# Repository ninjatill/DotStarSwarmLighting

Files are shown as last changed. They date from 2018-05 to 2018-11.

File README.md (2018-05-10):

# DotStar Swarm Lighting
Lighting objects made with "DotStar" LEDs which communicate with each other in a swarm.

**_This entire project is a major work-in-progress. The DotStar Swarm ecosystem has much potential but is worked on as a hobby. If you would like to contribute, submit an issue or pull request. Thanks for your interest!_**

## Concept and Background
This project was started with a desire to make a high-visual-impact decorations for use in public displays. The core component in all the display objects is the DotStar LED. DotStar is a name used by Adafruit for independently-addressable RBG LEDs using the APA102 chipset (2-wire SPI interface). A public display can have multiple DotStar objects which can be manipulated from a central controller over WiFi.

Why create this stuff? The inspiration came from a giant, 50+ foot-tall oak tree in my front yard. I want to decorate for the holidays but this tree is so massive it doesn't make sense to run strands of "twinkle" lights up into the tree. Twinkle lights are prone to burn-outs, you would need a hundred strands to make a visual impact in such a large tree, and as the tree grows the strands would need repositioned if wrapped around the trunk or branches. To start this idea, I first designed the "DotStar Ball" which was a fairly large, bright sphere of individually-addressable LEDs. The ball size I thought would have a proportionally large visual impact when compared to an ornament on say a standard-sized christmas tree. But one sphere in a large tree is not enough. So the idea was that I would make 10-20 of these balls and to add to the "cool-factor", they would need to have animations and be able to coordinate the animations amongst themselves or respond to external input.

## Major Project Components
There are numerous components to the project including:
- lighting objects (ball/sphere/cylinder, chain, etc.),

**_Not Yet Implemented_**
- local swarm controller (device on the swarm network that sends commands to objects),
- external swarm controller (server or cloud app where you can build animations and send them to the local controller or objects).

## Project Elements with Documentation

- [Communication Structure](/CommunicationStructure.md)
- [The DotStar Ball](/DotStarBall/README.md)

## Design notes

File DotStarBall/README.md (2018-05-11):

# DotStar Ball (aka. DotStar Sphere)
The first object designed for this swarm ecosystem is the DotStar Ball (DSB). See the [DotStar Swarm Lighting readme](/README.md) for a full overview of what this project is all about.

//Add animated gif or video...

#### Design Criteria
When I started designing this object, I used the some of these criteria:
- had to be large enough to have a visual impact hanging on a large tree branch,
- had to be (relatively) low cost since I had to make many of them,
- has to receive external commands and display animations from that input,
  - commands should request a particular effect or animation as opposed to addressing individual pixels,
- has to be addressable individually or in groups,
- has to function autonomously after receiving commands (similar to how the DotStar APA102 chipset functions).

#### Design Constraints
- Anything I create has to live outdoors. It has to be designed to operate in Northeastern US weather (snow, rain, high-winds, etc.)
- I knew I would be using DotStar LED strips. I used them for a previous project and found them easy to use and program. These strips optionally come with a silicone jacket with an IP67 rating which satisfies the weather issue. To keeps costs low and with a rough guestimate of the size of the sphere, I chose the version with 60 pixels/meter which would give me a pixel length of 16.67mm.
- I have a 3D printer so I knew that I would most-likely design and print a custom support structure to keep it light and low cost. I have an original Prusa i3 Mk2 printer with maximum print dimensions 250x200x180mm.
- I wanted the electronics to be accessible without completely disassembling the ball. Also, for best WiFi reception, the electronics should be located on the under-side of the ball.

## Particle Photon Demonstration
Makers who do not want to build the DSB may still benefit from some of the demonstrated methods on the Particle Photon platform including:
- parsing JSON strings on the IoT hardware,
- receiving and parsing variables sent via JSON where the JSON payload contains a varying number of variables,
- using a single Particle cloud subscription to address multiple devices, filtering commands by a target address,
- using the built in Log functionality, sending logs to an external service such as papertrailapp.com,
- using classes for object-oriented programming on IoT devices,
- using both UDP and particle cloud functions to receive commands.

## Roadmap (To Do Features) (In _Loose_ Order of Priority)
- Add firmware features (sleep, report status to controller, etc.)
- Finalize designs for electronics custom PCB, electronics housing and hanging bracket.
- Investigate using hardware timers to control animation processing intervals.
- Add temperature monitoring/fan control for the PSU.
- Add support for external hardware triggers.
- Add environmental monitoring hardware making each light a small weather station.
- Add support for [DMX-512](https://en.wikipedia.org/wiki/DMX512).
- Add support for [Light-O-Rama](http://www1.lightorama.com/) controllers.

## Bill of Materials
- [Particle Photon](https://www.particle.io/products/hardware/photon-wifi) ($20)
- 10 Meters of SK9822 or APA102 LEDs, 60 Pixels/Meter, Silicone-Jacketed (IP67), Black Flex PCB (~$10/meter) from [Adafruit](https://www.adafruit.com/product/2239), [AliExpress](https://www.aliexpress.com/item/1m-5m-APA102-Smart-led-pixel-strip-Black-White-PCB-24-36-60-96-leds-pixels/32322326979.html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,searchweb201602_1_10152_10151_10065_10344_10068_10130_10324_10342_10547_10325_10343_10546_10340_5722611_10548_10341_10545_10696_5722911_5722811_10084_5722711_10083_10618_10307_5711211_10059_308_100031_10103_10624_10623_10622_10621_10620_5711311_5722511,searchweb201603_2,ppcSwitch_2&algo_expid=6ef3fe06-63bb-41f2-b8bc-39bc1ad5b3ed-1&algo_pvid=6ef3fe06-63bb-41f2-b8bc-39bc1ad5b3ed&priceBeautifyAB=0)
  - Reels of LEDs should come with extra 4-Pin JST connectors for connecting the electronics PCB to the LED strip.
- 3D-Printed Support Structure (~$48 for 2kg of PETG) (see the [readme](/DotStarBall/stl/readme.md) for more details.)
  - PETG 1.75mm Filament from [MakerGeeks](https://www.makergeeks.com/collections/maker-series-petg)
    - Choose appropriate filament for your 3D printer or have a 3D printing service manufacture the printed objects for you.
- 5V, 40A Switching Power Supply ($25) from [Amazon](https://www.amazon.com/ALITOVE-Transformer-Converter-Security-Computer/dp/B077SYHQCJ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)
- 6 2-pin Power Connectors ($10) from [Amazon](https://www.amazon.com/TrendBox-Connector-Adapter-Electronics-Projects/dp/B0722SCRHM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)
- Multi-colored Hookup Wire (size appropriately and consider outdoor exposure when selecting). Alternatively, use 4-conductor LED ribbon cable (I will probably use [this](https://www.amazon.com/TronicsPros-65-6ft-Extension-Connector-Multicolor/dp/B015RLUAV0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) on subsequent DSBs but I wanted a larger wire gauge for the power rails and also the power and ground should be the outer-most connectors.)
- Clear Silicone Caulking
- Solder
- 64+ #6 1/2" Stainless Steel Screws from [Fastener Mart](https://www.fastenermart.com/SC165-1452.html)
- 16+ #6 3/4" Stainless Steel Screws from [Fastener Mart](https://www.fastenermart.com/SC165-3452.html)

## Similar Designs
I mostly had the support structure designed and fabricated prior to doing any kind of search for a similar idea or concept. I did find a few similar designs out there but none that fit my exact requirements. Most were stand-alone objects and higher in cost to fabricate. Here's a brief comparison:
- [Spherical LED Matrix](http://www.instructables.com/id/Spherical-LED-Matrix-Sphere-Shaped-LED-Screen-From/) This project is most closely related to what I'm trying to do. The maker used a metal support structure and oriented the pixel strips in a horizontal manner (which I found to be an unfavorable design.) The maker hides the non-uniform LED positioning by enclosing the entire structure in a translucent shell.
  - This design differs from the DSB in that the DSB is smaller, lighter, and WiFi enabled. Both projects are similarly (proportionally) priced. Additionally, this design uses specialized hardware and uses non-wireless communication protocols/hardware such as USB or DMX-512. It is not addressable in a swarm but could be modified to do so. The device cannot function on its own but rather takes constant input from a software controller; while this doesn't meet my design goals, use of off-the-shelf software means that more animations and effects are available without custom programming.
- [Giant LED Disco Ball](https://blog.hackster.io/get-the-party-started-with-this-giant-led-disco-ball-cd776451e3c0) This is a well designed project that used custom-printed PCBs to create a geodesic sphere. Each PCB housed a few Neopixels. The design is meant to be mobile and run off of large LiPo batteries.
  - This design differs from the DSB in that the DSB is smaller, lighter, cheaper to fabricate and WiFi enabled. It is not addressable in a swarm but could be modified to do so.
- [Neopixel LED EyeBall](https://www.hackster.io/H0meMadeGarbage/neopixel-led-eyeball-8da098)
  - This is just a few Neopixels taped to a half-sphere meant to be carried around. Not exactly a comparison but it does come up when you search google for "LED Sphere".
- Hackster.io and Youtube.com have some DIY POV-type cylindrical and spherical displays such as [this](https://www.hackster.io/hanoba_DIY/pov-cylinder-with-arduino-due-7016d5), [this](https://www.hackster.io/wslaton/easy-pov-display-9f4a88), [this](https://www.youtube.com/watch?v=sEY6N4HkSDM), [this](https://www.youtube.com/watch?v=-1Qe17flj0U), or [this](https://www.youtube.com/watch?v=Pf4IyXFTvT4). [This design](https://www.youtube.com/watch?v=_hprsvsPpEI) was a interesting take on the POV display but POV would not be reliable in the same environment as the DSB.
  - POV displays would not be practical to hang in a tree due to the moving parts and exposed electronics. Any slip joint would be prone to water infiltration.
- Youtube.com has some commercial displays that are similar such as [this](https://www.youtube.com/watch?v=te4uvfAzgXY), [this](https://www.youtube.com/watch?v=v2Eh44Rp4_Q), [this](https://www.youtube.com/watch?v=sEY6N4HkSDM), or [this](https://www.youtube.com/watch?v=mB8hct78ETk).
  - All these projects look terribly expensive and out of reach for the DIY community.

## Sequences/Modes/Animations
Read the [Communication Structure](/CommunicationStructure.md) document for a better understanding of Sequences, Commands, Command Elements, and Parameters.

The following section documents the animations available on the DSB. A mode and animation are virtualy synonomous. However, a mode can specify some non-animation commands such as "standby".

Animations are pre-built for the light strip. Each animation is governed by the list of parameters sent in the mode command. See this reference for a list of the parameter types. An animation can be as simple as turning on/off a single pixel. But an animation can be complex such as a pulse (fade from a start color to an end color and then back to the start color).

The "M" mode command can trigger the following animations:

- (0) Standby
  - Runs the All Off animation once then waits for incomming commands. ~~If a duration is specified, the Photon will sleep for the specified duration.~~ (consider putting sleep-on-standby on roadmap).
- (1) All Off
  - Turns all LEDS off.
- (2) Object On
  - Turns on objects specified in the object array. 
  - Defaults to "All" if no object array specified. Defaults to black (off) if no color array specified.
  - Optional Parameters: A, C, O
  
  //Add animated gif or video...

- (11) Fade
  - Fades from one color to the next. 
  - The colors change slightly between the start and end color on each step advance. The amount of change is based on the number of steps (T) specified and the start and end colors. 
  - If repeat (R) is specified, on each repeat, the next 2 color in the color array will be used. If there are more repeats than colors, the color array index will wrap around.
    - For example, using this color array `"C":[0,255,65280,16711680]`
        1. On the first run the fade will go from 0 (black/off) to 255 (blue). 
        2. On the first repeat (2nd run), the fade will go from 255 (blue) to 65280 (green). 
        3. On the 2nd repeat (3rd run) the fade will go from 65280 (green) to 16711680 (red). 
        4. If there is a 3rd repeat (4th run) the start color will be 16711680 (red) and the end color will wrap around to the first color in the color array which is 0 (black/off). 
        5. If there is a 4th repeat (5th run), the fade will operate exactly as the first run.
  - Alternate/Sub Modes
    - Pulse - Fades up then fades down. Using this example `"M":11,"U":5000,"T":100,"R":1,"A":1,"C":[0,255,0]`, on the first run, the animation will start at color 0 (black/off) and ramp up to color 255 (blue) over 5 seconds and 100 steps (which is a pretty smooth transition). On the 2nd run, the animation will fade back to 0 (black off) over the same number of steps.
      - Pulse with high/low hold - Fades to a color, stays on that color before fading to the next color. Using this example `"M":11,"U":5000,"T":100,"R":2,"A":1,"C":[0,255,255,0]`, on the first run, the animation will start at color 0 (black/off) and ramp up to color 255 (blue) over 5 seconds and 100 steps (which is a pretty smooth transition). On the 2nd run, the animation will stay at color 255 (blue) for 5 seconds. On the 3rd run, the animation will fade back to 0 (black off) over the same number of steps.
  - Required Parameters: C
  - Optional Parameters: O, R
  
  //Add animated gif or video...

- (12) Fill
  - Fills the ball with a specified color in a sequential manner. Can be filled by columns, rows or pixels or any combination. The fill happens evenly over the course of the duration and steps. If only 1 steps (T) is specified, this would essentially work identical to Object On but in a much less efficient manner.
  - The object array specifies the starting point for the fill operation. Multiple objects (even of differing types) can be specified.       - For example, using this object array `"O":["C0","C11","R0"]`, on the first step, columns 0 and 11 and row 0 will turn on. On the 2nd step, columns 1 and 12 and row 1 will turn on. On the 3rd step, columns 3 and 13 and row 3 will turn on. Etc.
  - Example: `{"ABC":{"M":{"M":12,"U":1000,"T":24,"C":[255],"O":["C0"]}}}` fills the ball by columns over the period of 1 second. Each column will light sequentially starting with column 0 every 33ms until all columns are on.
  - Alternate/Sub Modes
    - Vertical Spin - The width parameter specifies the number of objects to keep on. Using this example `"O":["C0"],"I":0,"H":5`, the animation will keep 5 columns lit starting with column 0 and will spin in the clockwise direction.
    - Twinkle - Twinkle is a random lighting of pixels. On each subsequent step, a number of pixels are exchanged (some turned off, some turned on). Use "I":254 (randomized direction) and "H":xxx (number of objects on) in conjunction for a twinkle effect. You can twinkle by column, row or pixel.
  - Required Parameters: O, C
  - Optional Parameters: A, I, H
    
  //Add animated gif or video...
  
- (13) Spin
  - Spins either vertically or horizontally. A "spin" is a sequential lighting of objects in a particular direction. The Vertical spin is just a wrapper around the fill mode with a width. Spinning a single pixel (or group of pixels) or spinning horizontally (row spin) requires a custom routine.
  
  //Finish coding...
  //Add animated gif or video...
    
- (14) Flash
  - Flash starts with a solid color and then shows another color at full brightness for a very brief amount of time before returning to the original color.
  
  //Finish coding...
  //Add animated gif or video...
    
## Design Walkthrough  
My first CAD iterations used a solid spherical shell with LEDS in horizontal rows and parallel to the ground. In order to make animations easy to design in software, I knew it would be best to use the same number of LEDs in each row/column. Once I saw the first design in TinkerCad.com, I knew I would have problems laying the flat ribbons horizontally as they would not conform to the sphere well. When horizontal, each strip would be a different length and my sphere might start to look like a stepped cylinder rather than a sphere. Then I started to lay them out in a vertical orientation. This was a much better design as the strips could all be uniform in length. Since the max dimension of the 3D printer is 250mm, that was my starting sphere radius but I could only print half a sphere. Each vertical "arm" was rotated around the z-axis in order to create the sphere. I chose to include 24 verticals to have a fairly dense pixel spacing. All in, that would be 23 pixels * 24 strips = 552 pixels. 
  
Because of the strip width (14mm), each vertical couldn't converge directly in the center of the north/south poles. I would have to space the vertical strips so that they converged on top and bottom support rings and design a fastening system. The strips looked nice when I layed them out around a 100mm diameter ring. I decided to fasten all these 3D printed vertical "arms" to the rings using stainless steel screws. So now I have a segmented shell that looks a bit like a torroid rather than a sphere... but it's not that noticable (unless you ask my wife which calls it the "LED pumpkin.")
  
I looked for a power source that could handle the 552 LEDs and fit within a 250mm sphere. At this point, I already ordered the LED strips from AliExpress. They are based on the SK9822 chipset (which is apparently a better knock-off of the APA102 chip). I had a few 1 meter prototyping strips from Adafruit but I needed approximately 9.2 meters for this project. Using AliExpress lowered the cost to approximately $10/meter as opposed to using Adafruit at approximately $40/meter. The LEDs represent the single biggest cost in the bill of materials. To calculate the total power usage using the (not very clear) datasheet, I used a worst-case value of 20ma/color/pixel * 3 colors (RGB) * 552 pixels = 33.12 amps total current at 5 volts. Of course you should always oversize a PS so you run at about 80% of maximum capacity to account for spikes. The outdoor power supplies (PS) on Amazon looked expensive and didn't fit my desired footprint. I chose a ~$17 40A, 5V internal PS from Amazon. Going by the specified PS dimensions, I could now design a housing for it. The design was a bit tricky and I printed several partial designs on the 3D printer to make sure it would print right. To shorten a very long story, I ended up using a multi-part/modular cylinder design printed in PETG to act as the internal support structure. The PS would be encased in this cylinder and not accessible after the DSB is assembled. I included an side-opening and rain shield to accomodate a 30mm fan for ventilation. I anticipate incorporating a temperature sensor within the PS housing which activates the fan when needed.

After cutting the LED reels into 23-pixel columns, I soldered them all together with hook-up wire incorporating 6 power taps (one tap every 4 columns.) The strips are wired in a daisy chain where the dataflow is "up" on the first strip and then "down" on the second strip and alternates in that manner for the entire length of the chain. To attach the strips to the support structure, I anticipated simply using zip ties (they are low-cost, expendable, and they work). However, the zip tie crushed the silicone jacket excessively and I anticipated issues with the silicone breaking or leaking over time. So I went back to the 3D printer and created hundreds of clips using crystal clear PETG (to be light transparent). The clips held the silicone snugly to the support structure. The larger of the 2 clips I designed had detents so that you could put a zip tie around both the support structure and clip for a more snug fit without crushing the silicone jacket.

## Assembly
1. Start by assembling the power supply. Install the main power feed and the LED strip power connections. You may want to run a functions check prior to encasing the power supply in the support structure; hookup the power supply, LED strip and electronics and run through some animations.
2. Assemble the 3D printed objects. See the [readme](/DotStarBall/stl/README.md) in the stl folder for a detailed write up on just the 3D printed components.
3. Solder the LED strip together. The process involves cutting the 5m reels into 23-pixel strips. Then soldering 4 wires between each strip. You may want to wait until running an electrical function check prior to injecting silicone in each end of the strips.
4. Affix the LED strip to the support structure using clips. Start with the first strip and work your way around the ball. You may want to put a small amount of silicone caulk behind the strip to more permenantly affix the strip to the support structure. If you don't use silicone, the strip may have a tendancy to slip over time due to vibrations (depends on how many clips you use as well.)
5. Connect the LED strip power connections to the power supply.
6. Assemble the electronics PCB to the electronics housing.
7. Connect the electronics PCB to the LED strip 4-pin JST connector.
8. Affix the electronics housing to the underside of the support structure. Take care to ensure all power cables are tucked up into the ball and do not put excess force on any electronic components.
9. Affix the hanging bracket to the top of the ball.

## Installation In a Lighting Display
Note: For complex animations, the DSB will most likely be driven by a controller using UDP networking. Because UDP does not guarantee delivery of packets (it's more of a "best effort" service), you must ensure the DSB is connected to a reliable and "quiet" network (minimal UDP/multicast/broadcast traffic). To ensure the best reliability, provid a dedicated WiFi access point or router and place all DotStar swarm components in a private VLAN. In order for DSB components to communicate with each other, they must all be on the same network subnet. In order to use Particle Cloud communication, all DSB components must also be able to contact the internet.

1. Install the assembled ball in your lighting display. (Depending on the setup, this may include associating the Particle Photon to a new WiFi network. You should complete the WiFi association before installing the ball in its final location.)

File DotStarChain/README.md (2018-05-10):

# DotStar Chain

//...Work in progress... Working on 3D rendering. Most likely will be in a "snowflake" pattern (not super stoked about that but that's what it kinda looks like.) Connect multiple single links together for a longer chain to wrap around the tree. Each link will be an 8 point star pattern that operates opn the same opposing-directions daisy-chained strip like the DotStar Ball (except that multiple links will be addressed by a single uController.)

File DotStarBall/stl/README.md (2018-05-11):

# 3D Printed Objects for the DotStar Ball (DSB)
All components were designed in [TinkerCad](https://www.tinkercad.com/#/) and printed on a [Prusa i3 Mk2](https://www.prusa3d.com/). Filament used was [MakerGeeks PETG](https://www.makergeeks.com/collections/maker-series-petg) at 255°C with a heated bed at 80°C. All .STL files were sliced on [Sli3er Prusa Edition](https://www.prusa3d.com/slic3r-prusa-edition/) 1.39.1 or better.

## Components
1. **Power Supply (PSU) Cylinder** (5 components)
   - This is the internal support structure for the DSB. The cylinder has an internal rectangular slot which accepts a 5V, 40A power supply. The cylinder is modular with 3 parts (top, mid, bottom). The parts are overlapping for an [IP 42 rating](https://en.wikipedia.org/wiki/IP_Code) (does not allow downward falling rain or snow within the enclosure.) 
   - The PSU cylinder was designed to be modular for flexibility if creating a larger DSB. For example, I already designed a 500mm diameter ball. To accomodate the larger size, the top and bottom cylinders can be reused an only the mid cylinder needs to be modified, or more easily, add additional mid cylinder pieces to make up the additional length. The mid cylinder for the 250mm DSB is 150mm tall. To accomodate the 500mm DSB, you would need a total of 350mm's of mid cylinder; because it is a modular design, you use two 150mm cylinders and add an additional 50mm cylinder piece.
   - **Top Cylinder**
     - This top-most portion of the PSU cylinder has 24 mounting holes for attaching LED arms with [#6-1/2" stainless steel self-tapping screws](https://www.fastenermart.com/SC165-1452.html). The top cylinder is labeled as 57mm which is the actual length of the piece. There is a 10mm overlap with other pieces which provides the weather-proof design.
     - Recommended Print settings: .2mm layers, 5 solid layers top and bottom, 3 perimeters, 25% infill or more, supports off. Must be printed with the smaller diameter end touching the build plate.
   - **Mid Cylinder**
     - Note: Cylinder pieces are labeled with actual length which is 10mm more than the length contributed to the overall PSU cylinder. There is a 10mm overlap with other pieces which provides the weather-proof design.
     - 160mm w/ fan - This mid-span portion of the PSU cylinder has mounting holes for a 30mm case fan. It is meant to be a modular piece for creating a larger DSB. When installing a fan, you should install a small mesh screen between the fan and cylinder to give it the IP 42 rating. If a mesh screen is omitted, bugs and other particulates may infiltrate the cylinder. 
     - 160mm plain - This mid-span portion of the PSU does not have any holes for fans or other components. It is meant to be a modular piece for creating a larger DSB.
     - 110mm w/ fan - This mid-span portion of the PSU has mounting holes for a 30mm case fan. It is meant to be a modular piece for creating a larger DSB. When installing a fan, you should install a small mesh screen between the fan and cylinder to give it the IP 42 rating. If a mesh screen is omitted, bugs and other particulates may infiltrate the cylinder. 
     - 110mm plain - This mid-span portion of the PSU does not have any holes for fans or other components. It is meant to be a modular piece for creating a larger DSB.
     - 60mm plain - This mid-span portion of the PSU does not have any holes for fans or other components. It is meant to be a modular piece for creating a larger DSB.
     - Recommended Print settings: .2mm layers, 5 solid layers top and bottom, 3 perimeters, 25% infill or more, supports off. Must be printed with the smaller diameter end touching the build plate.
   - **Bottom Cylinder**
     - This bottom-most portion of the PSU cylinder has 24 mounting holes for attaching LED arms (same as top cylinder). Also has a large hole for power cable access. Although you may be able to touch the PSU from this access hole, you should install the power cables to the PSU before encasing the PSU in the cylinder.
     - Recommended Print settings: .2mm layers, 5 solid layers top and bottom, 3 perimeters, 25% infill or more, supports off. Must be printed with the smaller diameter end touching the build plate.
   - **Fan Shroud**
     - The fan shround should be mechanically fastened and then sealed to the cylinder to prevent water infiltration. The shroud must be sealed to the cylinder with silicone caulk (removable), epoxy (permanent), or other desired method.
     - Recommended Print settings: .2mm layers, 4 solid layers top and bottom, 2 perimeters, 25% infill or more, supports off. Must be printed with the flat surace (top of shroud) touching the build plate.
   - **PSU Spacer**
     - The internal PSU slot was oversized to house a variety of PSU sizes. As such, it requires a spacer to keep the chosen PSU from moving within the cylinder. You can design a custom spacer for your PSU or use some other method to stop the PSU from moving.
     - Recommended Print settings: .2mm layers, 2 solid layers top and bottom, 2 perimeters, 10% infill or more, supports off.
2. **LED Arm**
   - The LED arm is 3mm thick and has holes on either end for attaching to the PSU cylinder. Version 2 has nubs on the back side designed to keep the LED clips from sliding down the arm. A small amount of material may have to be shaved off of the surfaces where the arms touch each other because of enabling supports.
   - Recommended Print settings: .2mm layers, 4 solid layers top and bottom, 2 perimeters, 25% infill or more, supports on with "Support on Build plate only" enabled. Must be printed so that the curved edge (side of arm) is touching the build plate (it will look like a "C" when viewed from above.)
3. **LED Clips**
   - There are 2 versions of the clip: a 3mm wide version (plain) and a wider 5mm version with indents to keep a 2mm zip tie centered on the clip (zip style).
   
**_Not Ready for Posting_**

4. **Electronics Housing**
   - The electronics are contained in an enclosure bolted to the bottom of the DSB.
   
5. **Hanging Bracket**
   - The DSB is desined to be hung from a branch. The hanging bracket bolts to the top of the unit without any penetrations into the PSU cylinder internal cavity. The bracket may have to be constructed from a sturdier material such as aluminum.
    
## Assembly
Before assembling any 3D printed objects, prepare the power supply by installing the main power feed and the power tap connections for the LED strips.

Note: After printing the top cylinder, inspect the top-most solid surface for water tightness. If the solid surface looks porous, you may want to apply a thin film of epoxy to ensure water tightness. Gorilla Glue 2-part epoxy works well but ensure the epoxy completely dries (24-hours) before installing the LED arms.

1. On the mid cylinder, install a small piece of mesh screen to cover the side-hole and mount the fan directly over the mesh. (The fan is not required but is a good idea for thermal management especially in hotter environments. If you choose not to include a fan, you should still cover the side hole with mesh to keep out insects and dust.) Ensure the mesh does not impede fan movement and route the fan power cable into the cylinder through the side-hole (you may have to poke a small hole in the mesh or trim the mesh to allow the cable to route inside. After the fan is installed securely, install the fan shroud on the outside of the mid cylinder. Apply a small amount of silicone caulk to the mating surface of the shroud and then fasten the shroud to the mid cylinder with #6 1/2" stainless steel screws. _Do not overtighten the screws!_ Ensure the shroud is oriented so that it will shed rain and not collect it when assembled with the other cylider parts.
2. Align the top cylinder with the mid cylinder (there is an indented line running the vertical length of all cylinders that needs to be aligned.) Affix the top cylinder to the mid cylinder with #6 1/2" stainless steel screws. You may want to apply a small amount of caulk where the cylinders touch as well as in the screw holes to prevent water infiltration.
3. Insert the assembled power supply into the bottom cylinder. Route all power cables through the internal cavity and out the bottom access hole. Insert the power supply spacer inbetween the power supply and the cylinder slot (if you do not use the printed spacers, you must pack some material inbetween the cylinder and the power supply to prevent movement. Use material that will not catch on fire when exposed to the elevated temperatures of the power supply.)
4. Align the top/mid cylinder assembly with the bottom cylinder (using the exterior alignment markings). Fasten the top/mid cylinder assembly to the bottom cylinder with #6 1/2" stainless steel screws. You may want to apply a small amount of caulk where the cylinders touch as well as in the screw holes to prevent water infiltration.
5. Affix the arms to the top and bottom cylinders with #6 1/2" stainless steel screws. One method to ensure proper alignment is to install 2 arms directly overtop of the cylinder alignment marks. Next, install 2 arms at 90° from the first 2. Then, work on one quadrant at a time first affixing the top screws for all 5 arms, then turning the ball over and affixing the bottom screws for all five arms; repeat for each quadrant. You may want to apply a small amount of caulk in the top screw holes as added protection from water infiltration.

## Images

### 3D Renders (Tinkercad)

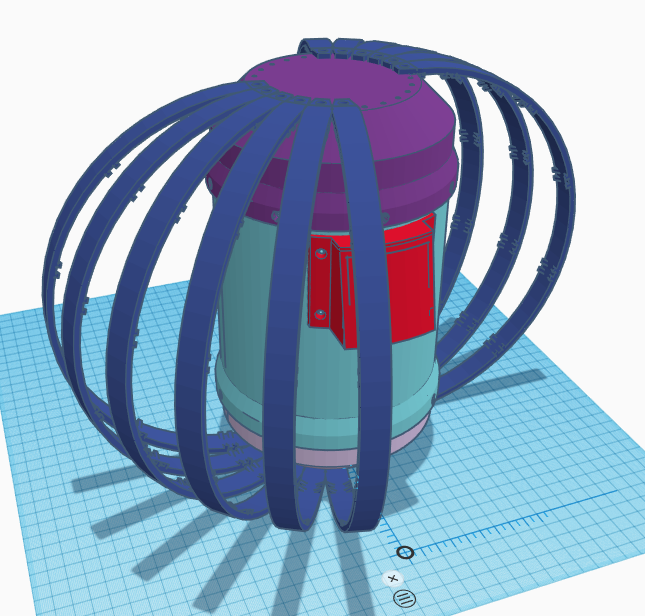
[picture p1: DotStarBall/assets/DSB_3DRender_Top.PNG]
3D Render - Top View

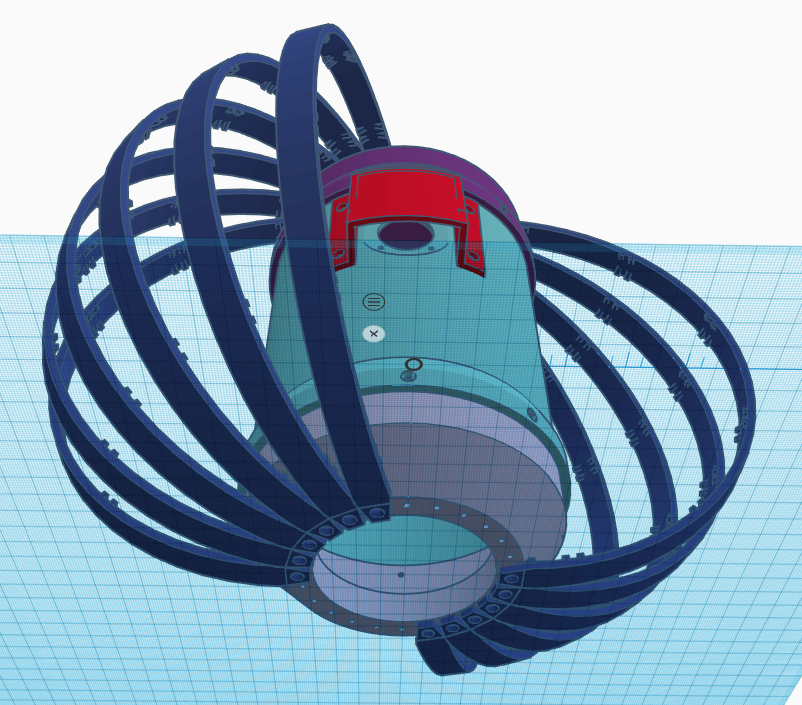
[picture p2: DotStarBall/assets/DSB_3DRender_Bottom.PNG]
3D Render - Bottom View


### Early Prototypes

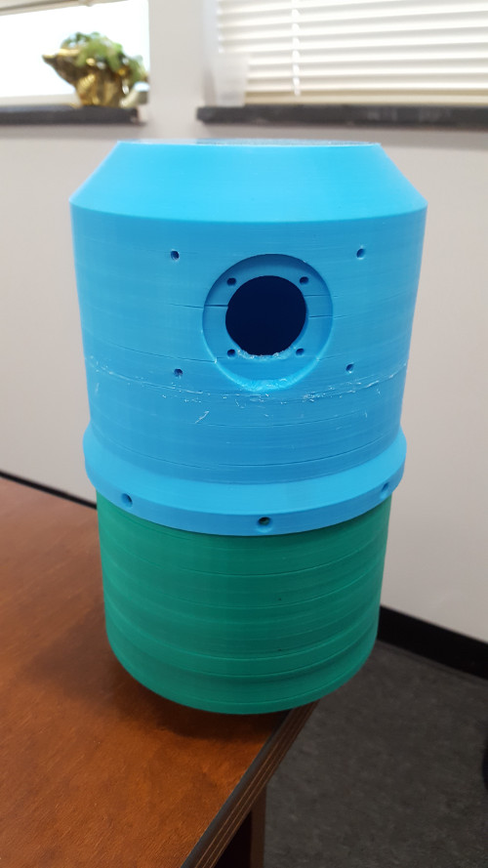
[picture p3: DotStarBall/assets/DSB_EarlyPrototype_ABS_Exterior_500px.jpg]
Early Prototype - DSB Cylinder Exterior - in ABS

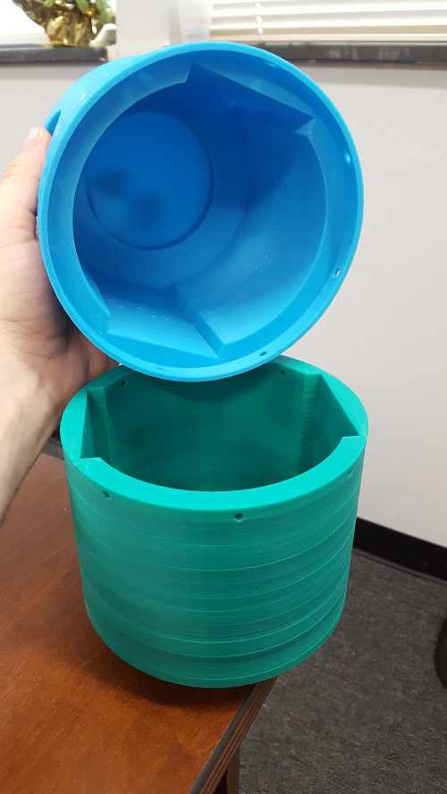
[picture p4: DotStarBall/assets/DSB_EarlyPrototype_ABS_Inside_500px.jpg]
Early Prototype - DSB Cylinder Interior - in ABS


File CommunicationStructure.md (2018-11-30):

# Communication Structure
Messages are send to the DS swarm (DSS) devices using JSON. The JSON object has 3 distinct containers that are used by the DSS: root, target, and command. Each command contains parameters which govern device behavior or animations. One JSON string could have multiple targets, each containing multiple commands, each containing multiple parameters. The JSON format is:

Basic single-command:
```
{                                     //root object start
  "[target id]": {                    //target 1 object start
    "command type": {                 //command 1 object start
      "[param type]":[param value],
      "[param type]":[param value],
      "[param type]":[param value],
    }                                 //command 1 object close
  },                                  //target 1 object close
  
  "[target id]": {                    //target n object start
    "command type": {                 //command 1 object start
      "[param type]":[param value],
      "[param type]":[param value],
      "[param type]":[param value],
    }                                //command 1 object close
  }                                  //target n object close
}                                    //root object close

```

Basic sequence command:
```
{                                     //root object start
  "[target id]": {                    //target object start
    "sequnce command type": [         //sequence array start
      { "[command type]": {           //command object 1 start
        "[param type]":[param value],
        "[param type]":[param value],
        "[param type]":[param value],
      },                              //command object 1 end
      { "[command type]": {           //command object n start
        "[param type]":[param value],
        "[param type]":[param value],
        "[param type]":[param value],
      }                               //command object n start
    ]                                 //sequence array end
  }                                   //target object close
}                                     //root object close

```

With a basic command, as shown above, you can target multiple swarms and each command contained within will be executed immediately. With a basic sequence command, as shown above, you can also target multiple swarms but each command contained in the sequcne array, is loaded into memory on the device. Depending on the type of sequnce command (see Command Types below), the sequnce may or may not execute immediately.

## Targets
Each DSS device is assigned a "Swarm ID" (SID) which is a string of alphanumeric characters. Each character in the SID denotes a sub-grouping of devices. Currently only 3 characters are used: `"[major swarm group][horizontal group][vertical group]"`. If future functionality requires it, the code is flexible enough to easily add additional characters for more sub-groupings.
- For example, imagine multiple DSS devices in a tree. If you wanted to run an animation where the devices rapidly lit from bottom to top, you could group all the devices in the tree by assinging them to major swarm group "A". In this scenario, the horizontal grouping is inconsequential so you could use the wildcard character "-". And for the vertical grouping, the bottom most device would be in vertical group "A", next device up would be in vertical group "B", next device up would be in veritical group "C", etc. When you design the animation you would send an "all on" mode command to each SID with a slightly larger delay parameter for each. Example SIDs: `"A-A"`, `"A-B"`, `"A-C"`. See the example "Sequential Rapid Lighting" for a working example.
- To expand on the example above, if you had multiple trees in your yard and wanted to rapidly light those trees in sequence, then the devices in each tree would be assigned a different major swarm group. To target the first tree use `"A--"`, second tree `"B--"`, etc.

```txt
            Tree 1                     Tree 2

V  E |       ***           V  E |       ***
e    |    **     **        e    |    **     **
r  D |   *         *       r  D |   *         *
t    |   *         *       t    |   *         *
   C |    **     **           C |    **     ** 
     |      |   |               |      |   |
G  B |      |   |          G  B |      |   |
r    |      |   |          r    |      |   |
p  A |     /     \         p  A |     /     \
     __________________         __________________
        A  B  C  D  E              A  B  C  D  E
	
      Horizontal Group           Horizontal Group

        Major Group A              Major Group B
```

## Command Types
When sent individually, these are referred to as a "command". When sent as part of a sequence, then it is a "command element".
- "M" - Mode commands contain parameters for setting up and running an animation.
- "R" - Repeater element. *Can only be used as a sequence command element.* The repeater tells the sequence to repeat the last x number of command elements, y times.
- "S" - Settings update command. Updates devices settings such as global brightness, time zone offset, etc.
- "X" - Execute command. Modes have a "wait to execute" flag that makes the mode wait for an "execute command" before processing. 
  - The execute command was envisioned as a way to coordinate the start of an sequence/mode/animation to account for processing or message propogation delays. Also, imagine a public display where a user could press a button, or send a text, etc. to start either a mode or sequence; an external device or server will send the execute command when that user input is received.

#### Sequence Commands
- "Q" - A self-contained sequence command. Enclosed command elements will replace any pre-existing sequence and the sequence will immedately start processing.
- "QS" - Contains the first part of a new multi-message sequence. A new sequence is created and then waits for additional messages which add on to the sequence. The sequence will not process until a "QE" command is received.
- "QA" - Contains additional elements to add onto a multi-message sequence command. Can be used to add onto a already processing "Q" command. Does not start the sequence processing. If the sequence was already processing, the sequence will continue to process.
- "QE" - Contains the final/end elements to add onto a multi-message sequence command. The sequence will begin processing after a "QE" command finishes parsing.

## Parameter Types
There are 2 types of parameters: required, and mode-specific. Required parameters are required for every mode command sent. Mode-specific parameters, as the name implies, are optional parameters that a mode uses to tailor the animation. Parameter types are always wrapped in double-quotation marks. For parameter values:
- if it is a string, the it must be wrapped in double-quotation marks,
- if it is a number, then the number is sent as-is without wrapping quotation marks,
- if it is a boolean, then the value should be true or false without any wrapping quotation marks.

### Parameters Explained
Parameter list is in format: 
- `"[Param Char]" - [Param Name] - [Param Datatype]`
  - Animation description.
  - Important notes. (optional)
  - Values: (optional)
  - Example:

### Mode Parameters
#### Required Parameters
These parameters must always be specified. The mode will not display if they are omitted.
- "D" - Duration - unsigned long
  - Secifies the duration of the animation in miliseconds.
  - Example: `"U":5000` for 5000 miliseconds (5 seconds) total duration of the animation.
- "M" - Mode ID Number = uint8_t
  - Specifies the mode id number and associated animation to process.
  - Example `"M":11` for mode number 11 (fade).
- "T" - Steps - unsigned long
  - Specifies the number of steps in the animation and must be greater than 0.
  - Example `"T":5` for 5 total steps in animation.
  
Note: Duration (D) is divided by Steps (T) to calculate the refresh rate of the animation. For example, if you specify a duration of 1000 (1 second) and 10 steps, the animation will advance/process every 100 miliseconds (1000/10 = 100). The calculation is approximate because there is an estimated overhead of approximately 12 miliseconds between each refresh. The actual duration may be +/- several miliseconds. 

#### Optional Parameters
- "A" - Advance Color On - int
  - Specifies when to advance to the next color in the color array.
  - Values: 1 = on step advance, 2 = repeat advance.
- "C" - Color Array - Array of uint32_t
  - An array of colors to use. Colors are 32-bit integers but only the right-most 3 bytes are used to specify single-byte Red, Green and Blue values. It is best to convert RGB hexidecimal values to base10 decimals. For example, 0xFF0000 (red in hex) = 16711680 (red in base10).
  - To step through the color array, you must specify the "A" parameter. If no colors are specified, black (off) is assumed.
  - Example: `"C":[0,255,16777215]` for Black (off), Blue, White
- "D" - Start Delay - unsigned long
  - Number of miliseconds to delay before starting the animation. Delay can be used to coordinate "moving sequences" across members of the swarm.
  - Example: `"D":20` for a 20 milisecond delay before starting command.
- "F" - Fade Size - int
  - Number of elements to fade in animations such as spin, twinkle, rain, etc.
- "H" - Width - int
  - Specifies the width of an animation. Has different meaning depending on the animation; see animation description.
  - Example: `"H":5`
- "I" - Direction of Animation - uint8_t
  - Used for directional animations (spin, fill, etc.) to specify the direction of advance (when viewed from above). 
  - Values: 0 = CW/Up, 1 = CCW/Down, 2 = CW reverse on Step, 3 = CCW reverse on Step, 4 = CW reverse on Repeat, 5 = CCW reverse on Repeat, ... 254 = Randomize
  - Example: `"I":1` for Counter-Clockwise/Down direction.
- "L" - Tail Size - int
  - Size of the tail of the animation. ?!? needed ?!?
- "O" - Object Array - Array of Strings
  - An object can be a column (C) or row (R) of pixels or a single pixel (P). To explicity address all pixels, use "A" with any index (i.e. "A0"). String format should be `"[char for obj type][uint_16 for obj index]"`. The object index is zero-based.
  - Example: `"O":["C20","R8","P55"]` for Column 20, Row 8 and Pixel 55.
- "R" - Time to Repeat - int
  - Number of times to repeat the mode/animation. Use the max negative value of -2,147,483,648 for indefinite repeat. Use other negative values to specify a random repeat value.
  - Example: `"R":50` for reapeat 50 times. Note, this will display the mode 51 times since he first run does not count towards the repeat count.
  - Example: `"R":-500` to repeat a random number of times up to 500.
- "W" - Color Wheel Speed - uint8_t
  - If specified, the animiation will use a color wheel algorithm to step through the colors of the rainbow. The value governs the speed of the color transitions. Lower values will change slower than larger values.
  - Example: `"W":3` for color wheel enabled with a +/- 3-bit change on each color wheel advance.
- "X" - Wait for Execution - bool
  - Forces the mode to wait for an "execution" command before running the animation. This is designed to help coordinate timing / processing delays amongst the swarm.
  - Example: `"X":true` to set the wait for execution flag.

### Settings Parameters
- "B" - Global Brighness - uint8_t
  - Use to lower the overall brightness level of the swarm devices. 0 = 0%, 255 = 100%. The DotStar LED are intensely bright, so on a dark night without moonlight, you may want to lower the overall brightness to stave off neighbor complaints. 
- "D" - Debug Level - uint8_t
  - Changes the logging filter level for messages sent to the serial console and off-site log collection services.
- "I" - Multicast IP Address - Array[4] of uint8_t
  - Changes the Multicast IP Address the device listens for.
- "O" - Timezone Offset (from UTC) - int8_t
  - Used to change the timezone offset. Local time appears on some log messages and status reports.
- "P" - UDP Port - uint16_t
  - Changes the UDP port the device listens on. When changed, the device will re-initialize UDP.
- "T" - Daylight Saving Time Enable - bool
  - Enables (true) or Diables (false) daylight savings time. Time appears on some log messages and status reports.

## Creating A DS Swarm Command
1. First, create the root JSON container: `{}`
2. Next, target a swarm ID using a JSON object:  `{"A--":{}}`. The "A--" targets swarm "A", and has wildcards for the horizontal and vertical groupings. Therefore, every device in swarm "A" will respond to this command.
3. Next, 

## Command Examples

#### Settings Updates
- `{"A--":{"S":{"B":128,"O":-5,"T":true,"I":[239,1,1,240]}}}`
  - Targets SID "A--", brightness to 128 (50%), timezone offset to -5 (Eastern Standard Time), enables DST, multicast IP address to 239.1.1.240.

#### Basic Commands
- All On - `{"ABC":{"M":{"M":2,"U":5000,"T":1,"C":[16277215]}}}`
  - Sets devices with SID "ABC" to color white for a duration of 5 seconds. However, since there is no repeat command, the device will turn off (set color black) by itself. You must followup with an off command such as `{"ABC":{"M":{"M":2,"U":5000,"T":1,"C":[0]}}}`

- Blink - `{"A--":{"M":{"M":2,"U":5000,"T":2,"C":[255,0],"A":0,"R":50}}}`
  - Sets devices with SID "A--" to blue for 2.5 seconds and then off for 2.5 seconds. Repeats this 50 more times.

- Rapid Sequential Lighting (Vertical) - `{"A-A":{"M":{"M":2,"U":1000,"T":1,"C":[255]}}, "A-B":{"M":{"M":2,"U":1000,"T":1,"C":[255],"D":200}}, "A-C":{"M":{"M":2,"U":1000,"T":1,"C":[255],"D":400}}, "A-D":{"M":{"M":2,"U":1000,"T":1,"C":[255],"D":600}}, "A-E":{"M":{"M":2,"U":1000,"T":1,"C":[255],"D":800}}}`
  - Assuming you have a swarm with 5 vertical groups where group A is lowest and group E is highest: Turn on each vertical group from A to E with a 200 milisecond delay between each group lighting.

- Fade - `{"B--":{"M":{"M":11,"U":5000,"T":100,"C":[0,13320948],"O":["C0","C5","C11","C17","C23"]}}}`
  - Targets SID "B--" and fades 6 columns from off to purple in 5 seconds with 100 transition steps.

- Pulse - `{"B--":{"M":{"M":11,"U":5000,"T":100,"C":[0,13320948],"O":["C0","C5","C11","C17","C23"],"R":1,"A":1}}}`
  - Targets SID "B--" and faces 6 columns from off to purple in 5 seconds with 100 transition steps. Then immediately fades from purple back to off.

- Twinkle - `{"---":{"M":12,"U":1000,"T":5,"C":[16777215,0],"O":["P0"],"I":254,"H":110,"R":21600}}}`
  - Targest SID "---" (all devices in all swarms) and randomly lights 20% of the pixels to white. Every 200 miliseconds the first 20% turn off and the next random 20% turn on.

- Spin

#### Sequences
- Basic Sequence

- With Repeaters

- Rapid Sequential Lighting with Re-Synch on Next Mode

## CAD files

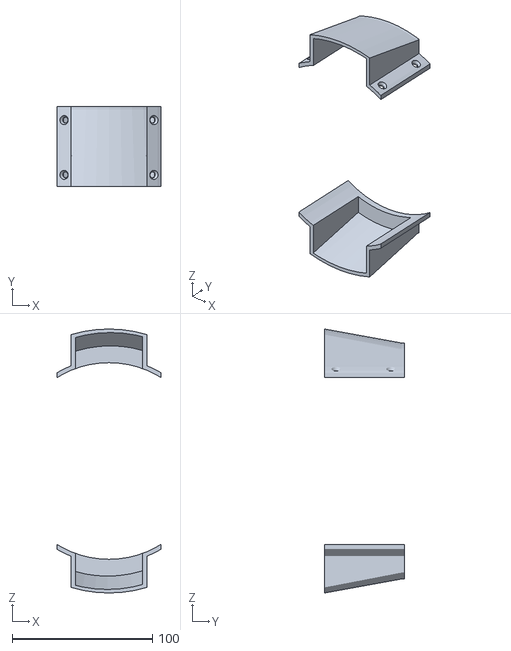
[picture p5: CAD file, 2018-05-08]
DotStarBall/stl/DotStarBall_FanShroud.stl
74.0 x 57.0 x 188.0

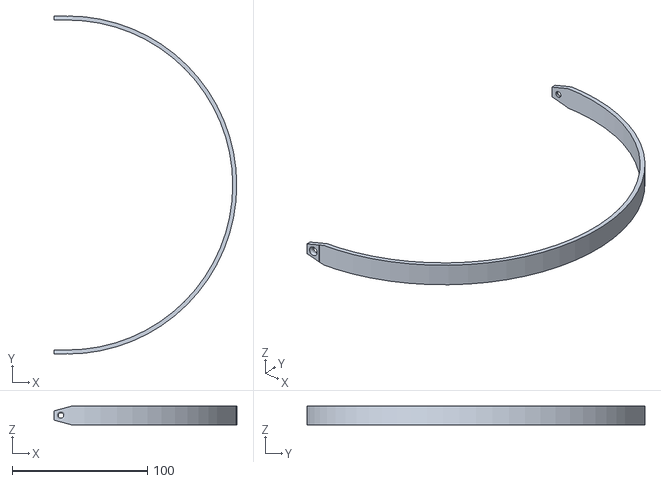
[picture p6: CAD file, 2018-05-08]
DotStarBall/stl/DotStarBall_LEDArm.stl
135.0 x 250.0 x 14.0

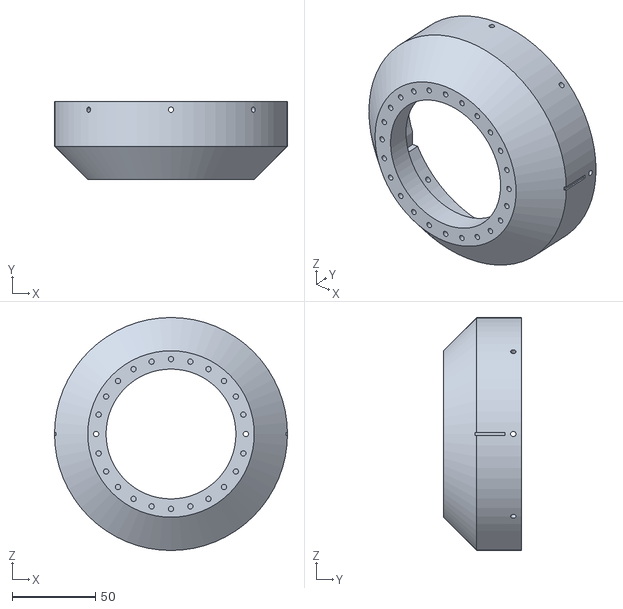
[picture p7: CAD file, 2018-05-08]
DotStarBall/stl/DotStarBall_PSUCylinderBottom_47mm.stl
140.0 x 47.0 x 140.0

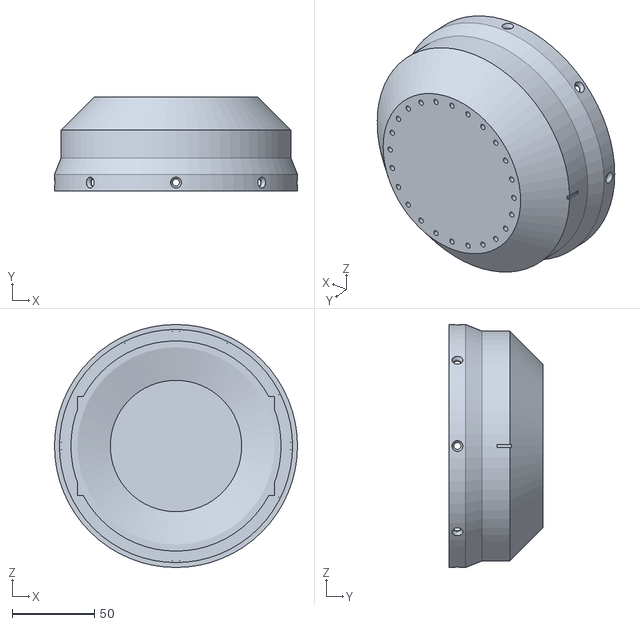
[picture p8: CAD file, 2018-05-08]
DotStarBall/stl/DotStarBall_PSUCylinderTop_47mm.stl
148.0 x 57.0 x 148.0

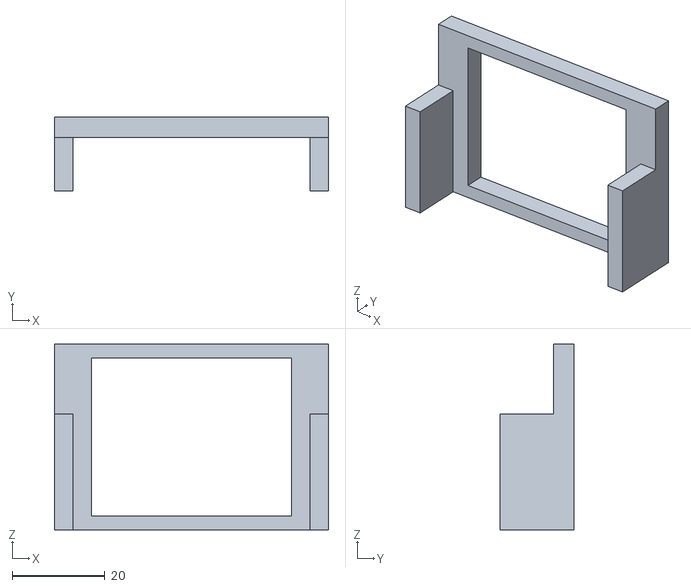
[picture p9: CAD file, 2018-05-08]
DotStarBall/stl/DotStarBall_PSUSpacer.stl
59.0 x 16.0 x 40.0

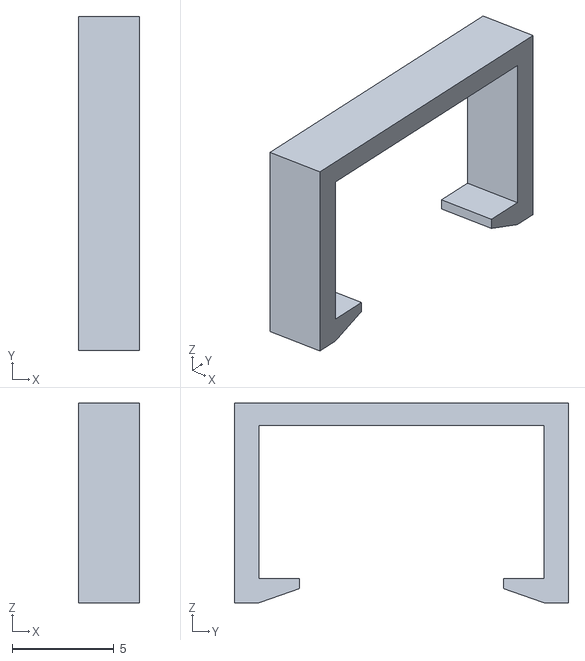
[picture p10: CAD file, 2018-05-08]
DotStarBall/stl/DotStarBall_LEDClips_Plain_v3.stl
3.00 x 16.4 x 9.80

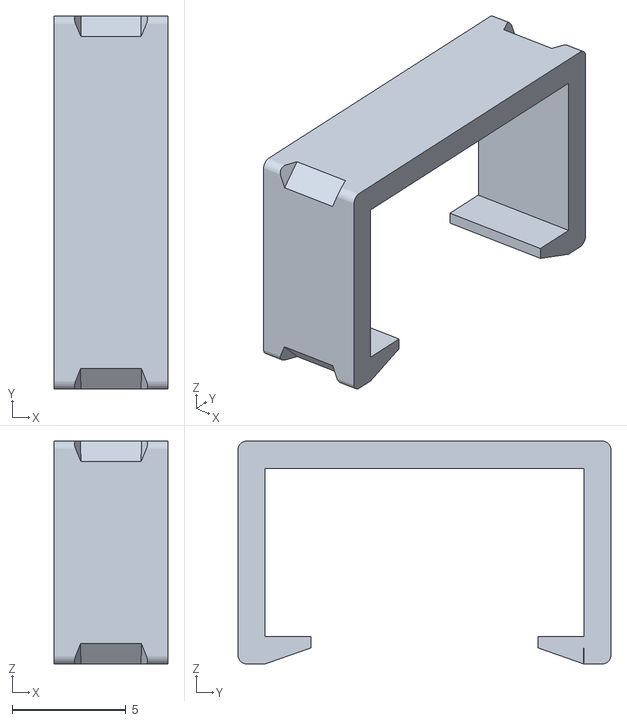
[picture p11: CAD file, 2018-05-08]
DotStarBall/stl/DotStarBall_LEDClips_ZipStyle_v3.stl
5.00 x 16.4 x 9.80

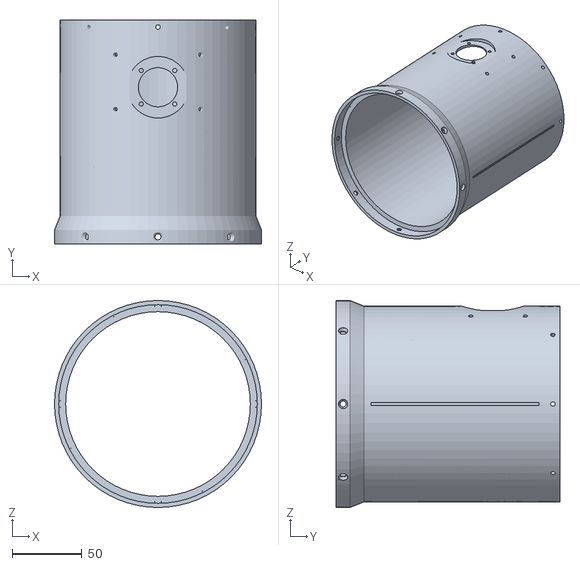
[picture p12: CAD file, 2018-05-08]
DotStarBall/stl/DotStarBall_PSUCylinderMid_wFan_160mm.stl
148.0 x 160.0 x 148.0

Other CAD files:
DotStarBall/stl/DotStarBall_LEDArm_v2_WClipNubs.stl

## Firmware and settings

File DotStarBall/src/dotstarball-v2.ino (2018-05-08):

#include "JsonParserGeneratorRK.h"

// This #include statement was automatically added by the Particle IDE.
#include "CmdProcessorv2.h"

// This #include statement was automatically added by the Particle IDE.
#include <papertrail.h>

// This #include statement was automatically added by the Particle IDE.
#include "Repeater.h"

// This #include statement was automatically added by the Particle IDE.
#include "Adafruit_DotStar.h"

// This #include statement was automatically added by the Particle IDE.
#include "Animations.h"

// This #include statement was automatically added by the Particle IDE.
#include "Settings.h"

// This #include statement was automatically added by the Particle IDE.
#include "Sequencer.h"

// This #include statement was automatically added by the Particle IDE.
#include "Mode.h"

SYSTEM_THREAD(ENABLED);
SYSTEM_MODE(SEMI_AUTOMATIC);

UDP Udp;

Settings s;
Mode mo(0);
Sequencer sq;

Adafruit_DotStar st(s.NumPixels);
Animations a(&s,&st);

SerialLogHandler logHandler(115200, LOG_LEVEL_TRACE);
//PapertrailLogHandler papertrailHandler("logs3.papertrailapp.com", 16247, "DotStar Ball", (const char*)(System.deviceID()), LOG_LEVEL_TRACE);

int LED = D7;
bool LEDOn = false;
char msg[255];
bool Resets[3]; //LED, Time, UDP
bool loopDebug[5] = {false, false, false, false, false};
int loopCount = 0;
char jsonString[1500];

void setup() {
    //Start Serial for debugging messages.
    Serial.begin(115200);
    
    //Initialize Reset Array.
    InitializeResets();
    
    //LED Strip Initialization.
    InitializeLEDStrip();
    
    //Indicate startup via D7 LED...
    pinMode(LED, OUTPUT);    // sets pin as output
    digitalWrite(LED, HIGH); // sets the LED on
    delay(1000);
    digitalWrite(LED, LOW); // sets the LED off
    
    //Wait for serial debugging for 10 seconds. Flash D7 for visual indication.
    if (s.Debug) {
        long LastMillis = millis();
        while(!Serial.isConnected() && ( (millis() - LastMillis) < 10000 ) )
        {
            if (!LEDOn) {
                digitalWrite(LED, HIGH); // sets the LED on
            }
            else {
                digitalWrite(LED, LOW); // sets the LED off
            }
            LEDOn = !LEDOn;
            delay(200);
            Particle.process();
        }
    }
    digitalWrite(LED, LOW); // sets the LED off
    
    //Setup local time for Eastern Standard Time (UTC-5) and enable Daylight Savings Time.
    InitializeTime();

    //Start receiving commands via particle cloud.
    Log.info("Subscribing to \"DSBcmd\" events.");
    //if (s.Debug) { Serial.println("Subscribing to \"DSBcmd\" events."); }
    Particle.subscribe("DSBcmd", CmdSubscribeHandler, MY_DEVICES);
    Particle.connect();
    
    //Start UDP for receiving commands via wi-fi. Must call after Particle.connect().
    InitializeUDP();

    //if (s.Debug) { Serial.println(); } //Spacer...
}


void loop() {
    
    //Check for newly received commands.
    UdpReceive();
    
    //Process sequence changes.
    if ( (sq.Active && !(sq.SequenceComplete)) || sq.AdvanceNow ) {
        if (sq.AdvanceNow) {
            Log.warn("Advancing Sequence (Forced).");
            sq.Advance();
        } else if (mo.Complete && mo.Repeat == 0) {
            Log.warn("Advancing Sequence on Mode Complete.");
            sq.Advance();
        }
    }
    
    //Process the animation.
    if (mo.Step > 0) { mo.Delay = 0; }
    if ( ((millis() - mo.LastRunMillis) > (mo.NextMillis + mo.Delay)) ) {

        bool adv = false;
        //Reset the mode if repeat is enabled.
        if (mo.Complete) { adv = mo.AutoReset(); }

        if (!mo.Complete) {
            Log.warn("Mode Tick @ %u. Step %u. RepeatCount %i", millis(), mo.Step, mo.RepeatCount);
            
            //Process the animation.
            if (mo.Step <= mo.Steps) { a.ProcessMode(&mo); }
            
            //Advance the mode to the next step.
            mo.StepAdvance();
            
            Log.trace("End of Loop. Free memory: %u", System.freeMemory());
            
            //loopDebug = {true, true, true};
            //for(auto &v: loopDebug) { v = true; }
        }
    }
}

void CmdSubscribeHandler(const char *event, const char *data) 
{
    strcpy(jsonString, data);
    Log.warn("DSBcmd message received at %s.", Time.timeStr().c_str());
    Log.trace("...Payload: %s", jsonString);
    ParseNew(jsonString);
    ProcessResets();
}

void UdpReceive() 
{
    //strncpy(jsonString, *data, s.UDPMaxPacketSize);
    //char *message[s.UDPMaxPacketSize];
    //const char *message;
    bool rxError = true;
    
    int size = Udp.receivePacket((byte*)jsonString, s.UDPMaxPacketSize-1);
    if (size > 0 && size < s.UDPMaxPacketSize) {
        jsonString[size] = 0;
        rxError = false;
    } else if (size < 0) {
        Log.error("UDP receive size error: size = %i", size);
        rxError = true;
        // need to re-initialize on error
        Udp.begin(s.UDPPort);
    } 
    
    //Message receive was success... parse it.
    if (!rxError) {
        Log.trace("UDP message received from %i : %i:", Udp.remoteIP(), Udp.remotePort());
        Log.trace(jsonString);
        ParseNew(jsonString);
    }
}

void ProcessResets() {
    if (Resets[0]) {
        //Reset LED strip.
        InitializeLEDStrip();
    }
    if (Resets[1]) {
        //Reset Time zone/DST
        InitializeTime();
    }
    if (Resets[2]) {
        //Reset UPD.
        InitializeUDP();
    }
    InitializeResets();
}

void InitializeResets()
{
    for (int i=0; i<arraySize(Resets); i++) {
        Resets[i] = false;
    }
}

void InitializeLEDStrip() {
    //LED Strip Initialization.
    if (s.Debug) { Serial.printlnf("Initializing LED strip with %i pixels.", s.NumPixels); }
    if (s.NumPixels != st.numPixels()) { 
        if (s.Debug) { Serial.printlnf("Updating strip length to %i pixels.", s.NumPixels); }
        st.updateLength(s.NumPixels); 
    }
    st.begin();
    st.show();
    st.setBrightness(s.GBright);
}

void InitializeTime() {
    //Setup local time for Eastern Standard Time (UTC-5) and enable Daylight Savings Time.
    if (s.Debug) { Serial.printlnf("Initializing Time Zome (%i) and DST (%i)", s.TimeZoneOffset, s.EnableDST); }
    Time.zone(s.TimeZoneOffset);
    if (s.EnableDST) { Time.beginDST(); }
    if (s.Debug) { Serial.printlnf("The current time is %s.", Time.timeStr().c_str()); }
}

void InitializeUDP() {
    waitUntil(Particle.connected); //Network must be connected before calling Udp.begin() per photon reference.
    
    IPAddress myIP = WiFi.localIP();
    Log.warn("Local IP: %s; SSID: %s; RSSI: %i", myIP.toString().c_str(), WiFi.SSID(), WiFi.RSSI());
    
    //If a Udp setting changed, stop Udp then restart.
    if (Resets[2]) {
        Log.warn("Stopping UDP.");
        Udp.stop();
    }
    
    //Start UDP for receiving commands via wi-fi.
    Log.warn("Starting UDP on Port %d.", s.UDPPort);
    Udp.begin(s.UDPPort);
    Log.warn("Joining Multicast at address: %s", s.MCAddress.toString().c_str());
    Udp.joinMulticast(s.MCAddress);
}

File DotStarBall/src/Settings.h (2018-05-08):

#ifndef __DOTSTAR_BALL_SETTINGS__
#define __DOTSTAR_BALL_SETTINGS__

#include "application.h"

class Settings {
    public:
    
        //********************
        //Variables
        //********************
        
        bool Debug = true; //Enables debugging messages to serial console.
        bool Trace = false; //Enables trace messages to serial console.

        uint8_t GBright = 32; //Global Brightness Level
        uint16_t NumPixels = 552; //Number of Pixels in Ball.
        uint8_t NumColumns = 24; //Number of Columns in Ball.
        uint8_t NumRows = 23; //Number of Rows in Ball.
        
        char SwarmID = 'A'; //Groups devices into a addressable swarm.
        char HGroup = 'B'; //Horizontal Grouping within Swarm
        char VGroup = 'C'; //Vertical Grouping within Swarm
        
        uint16_t UDPPort = 8023;    //UDP listening port.
        uint16_t UDPMaxPacketSize = 1500;   //Network MTU size.
        IPAddress MCAddress;   //Multicast Address for Receiving Commands
        
        int8_t TimeZoneOffset = -5; //Offset from UTC for current time zone.
        bool EnableDST = true;      //Account for Daylight Savings Time; True = yes.
        
        int EstimatedOverheadMillis = 12; //Estimate 12 ms for SPI and cloud overhead.
        
        //********************
        //Functions
        //********************
        Settings();
        
        String ToString();

};

#endif

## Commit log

2018-05-08 Add files via upload
    Initial Commit
    [DotStarBall_LEDArm.stl, DotStarBall_LEDArm_v2_WClipNubs.stl, DotStarBall_LEDClips_Plain_v3.stl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]
2018-05-08 Add files via upload
    added fan shroud
    [DotStarBall_FanShroud.stl]
2018-05-09 added assembly and installation
